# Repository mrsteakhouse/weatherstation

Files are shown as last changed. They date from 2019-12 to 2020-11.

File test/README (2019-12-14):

This directory is intended for PIO Unit Testing and project tests.

Unit Testing is a software testing method by which individual units of
source code, sets of one or more MCU program modules together with associated
control data, usage procedures, and operating procedures, are tested to
determine whether they are fit for use. Unit testing finds problems early
in the development cycle.

More information about PIO Unit Testing:
- https://docs.platformio.org/page/plus/unit-testing.html

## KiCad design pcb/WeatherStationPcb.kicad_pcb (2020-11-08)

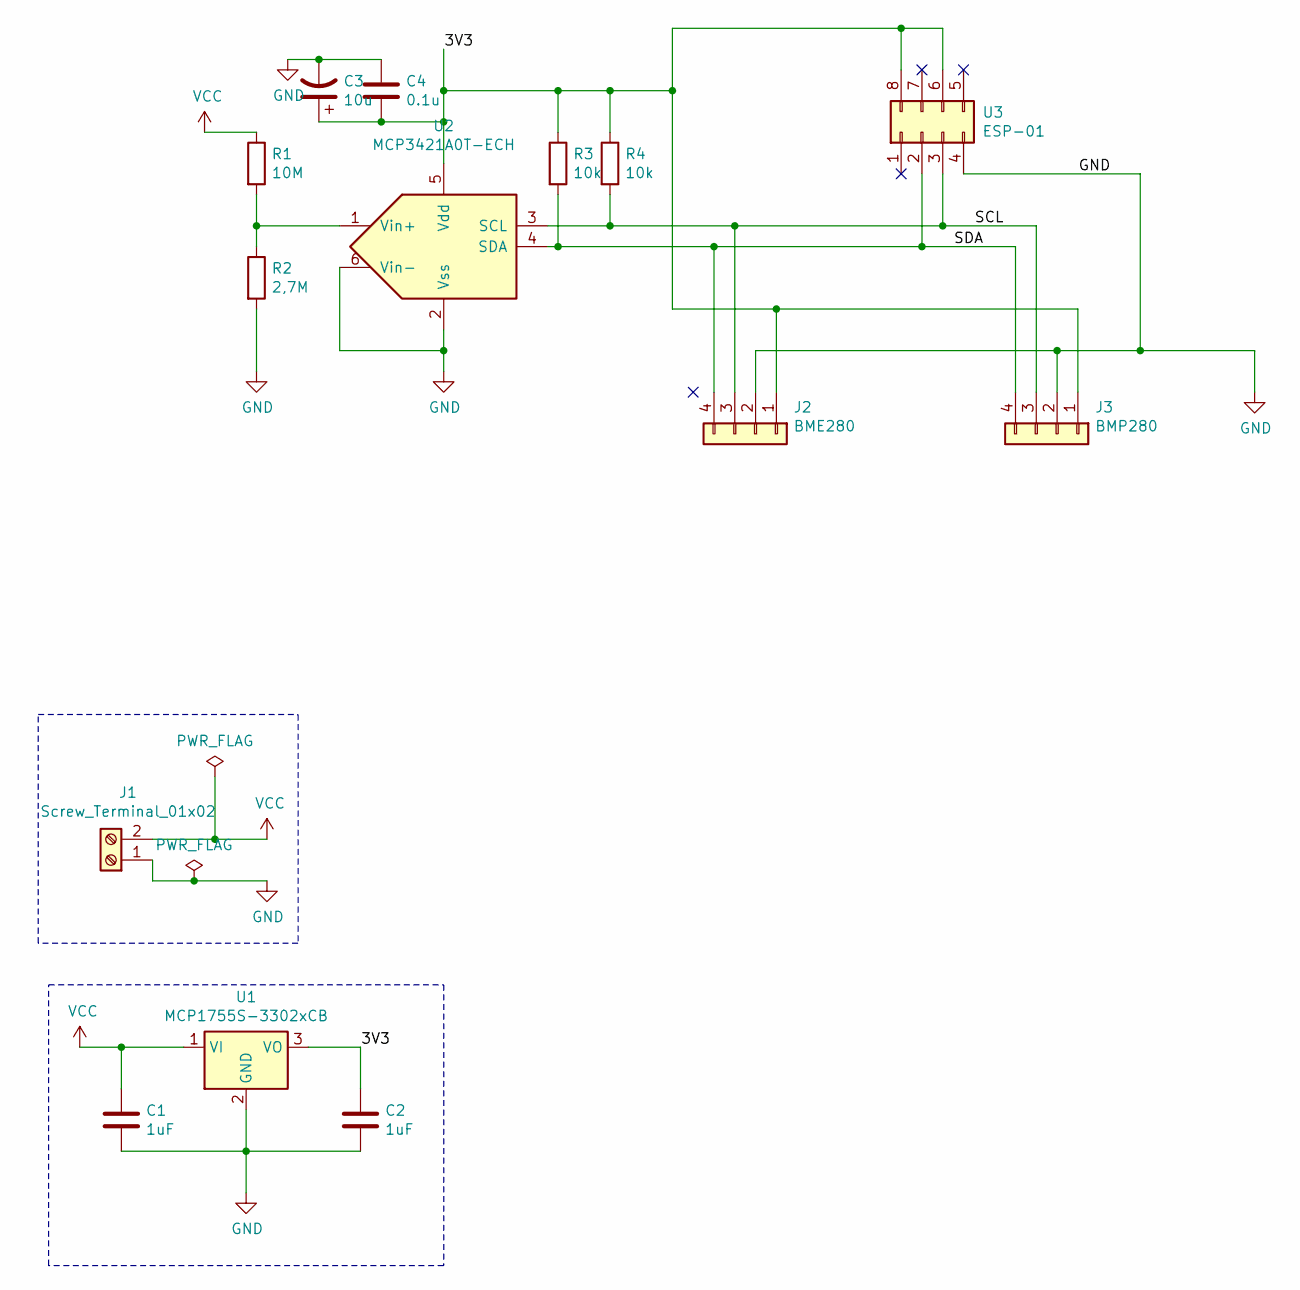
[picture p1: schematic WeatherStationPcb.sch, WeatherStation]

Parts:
C1, C2: 1uF; C_0805_2012Metric_Pad1.15x1.40mm_HandSolder
C3: 10u; CP_EIA-6032-28_Kemet-C_Pad2.25x2.35mm_HandSolder
C4: 0.1u; C_0805_2012Metric_Pad1.15x1.40mm_HandSolder
J1: Screw_Terminal_01x02; TerminalBlock_bornier-2_P5.08mm
J2: BME280; PinSocket_1x04_P2.54mm_Vertical
J3: BMP280; PinSocket_1x04_P2.54mm_Vertical
R1: 10M; R_0805_2012Metric_Pad1.15x1.40mm_HandSolder
R2: 2,7M; R_0805_2012Metric_Pad1.15x1.40mm_HandSolder
R3, R4: 10k; R_0805_2012Metric_Pad1.15x1.40mm_HandSolder
U1: MCP1755S-3302xCB; SOT-223
U2: MCP3421A0T-ECH; SOT-23-6_Handsoldering
U3: ESP-01

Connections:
/3V3: C2.1, C3.1, C4.1, J2.1, J3.1, R3.1, R4.1, U1.3 (VO), U2.5 (Vdd), U3.6 (CH_PD), U3.8 (VCC)
/SCL: J2.3, J3.3, R4.2, U2.3 (SCL), U3.3 (GPIO2)
/SDA: J2.4, J3.4, R3.2, U2.4 (SDA), U3.2 (GPIO0)
GND: C1.2, C2.2, C3.2, C4.2, J1.1, J2.2, J3.2, R2.2, U1.2 (GND), U2.2 (Vss), U2.6 (Vin-), U3.4 (GND)
unnamed: R1.2, R2.1, U2.1 (Vin+)
VCC: C1.1, J1.2, R1.1, U1.1 (VI)

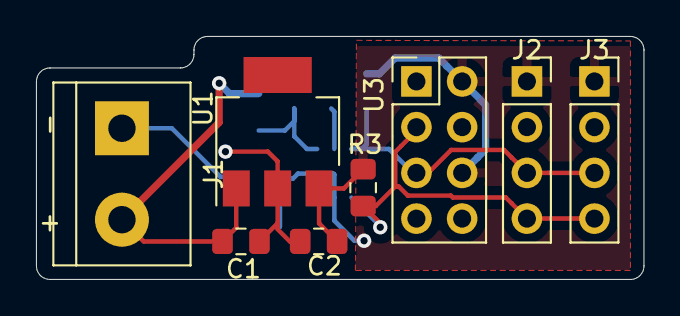
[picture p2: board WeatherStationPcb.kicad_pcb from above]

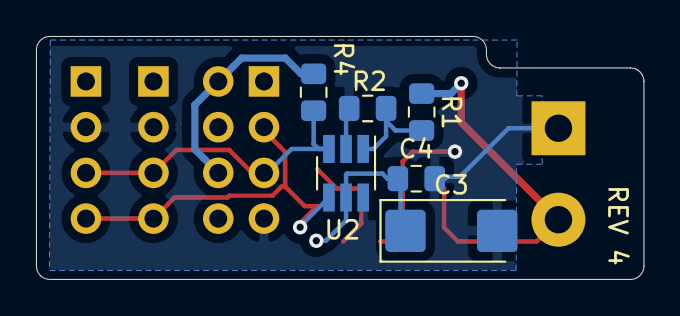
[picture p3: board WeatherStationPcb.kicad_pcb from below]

Board: 2 copper layers, 33.8 x 13.5 mm, 14 parts (6 on the bottom side), 6 nets.

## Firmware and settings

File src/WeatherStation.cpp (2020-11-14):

#include <ESP8266WiFi.h>

#include <WebThingAdapter.h>

#include <Wire.h>
#include <Adafruit_BME280.h>
#include <Adafruit_BMP280.h>
#include <Adafruit_Sensor.h>

#include <SetWifiCredentials.h>
#include <PubSubClient.h>
#include <sstream>
#include <MCP342X.h>

#define LSB 0.0000625
#define FACTOR 9.104

Adafruit_BME280 bme;
Adafruit_BMP280 bmp;

WiFiClient espClient;
PubSubClient client(espClient);

const IPAddress mqttServer = IPAddress(192, 168, 0, 59);

static const char *const DEVICE = "living-room-temp";
static const char *const TEMPERATURE_NODE = "temperature";
static const char *const TEMP_PROPERTY = "temp";
static const char *const HUMIDITY_PROPERTY = "hum";
static const char *const PRESSURE_PROPERTY = "p";
static const char *const BATTERY_PROPERTY = "bat";
static const char *const ALARM_PROPERTY = "alarm";
static const char *const PUMP_NODE = "pump";
uint64_t sleepTime = 3600e6L;

MCP342X adc;

void setupNetwork();

void setupSensors();

void setupAdapter(const IPAddress &ip);

void connectMqtt();

void updateValues();

void sendValue(const char* node, const char* property, const char* value);

void setupSleep();

std::string doubleToString(double number);

void setup(void)
{
    Serial.begin(115200);
    setupNetwork();
    IPAddress ip = WiFi.localIP();
    Serial.print(FPSTR("IP="));
    Serial.println(ip);

    setupSensors();
    connectMqtt();
}

void setupNetwork()
{
    setWifiCredentials();
    delay(20);

    WiFi.persistent(false);
    WiFi.mode(WIFI_STA);
    WiFi.setAutoConnect(false);
    WiFi.disconnect();
    IPAddress ip(192, 168, 0, 227);
    IPAddress gateway(192, 168, 0, 1);
    IPAddress subnet(255, 255, 255, 0);
    WiFi.config(ip, gateway, gateway, subnet);

    WiFi.begin(Ssid, Password);

    int retryCounter = 0;
    while (WiFi.status() != WL_CONNECTED)
    {
        delay(500);
        Serial.print(".");

        if (retryCounter >= 20)
        {
            ESP.restart();
        }

        retryCounter++;
    }

    Serial.println("");
    Serial.println(FPSTR("WiFi connected"));
}

void setupSensors()
{
    Wire.begin(0, 2);

    delay(1000);

    if (!bmp.begin(0x77))
    {
        Serial.println(FPSTR("Could not find a valid BMP280 sensor"));
        ESP.restart();
    }
    if (!bme.begin(0x76))
    {
        Serial.println(FPSTR("Could not find a valid BME280 sensor"));
        ESP.restart();
    }

    bmp.setSampling(Adafruit_BMP280::MODE_NORMAL,
                    Adafruit_BMP280::SAMPLING_NONE,
                    Adafruit_BMP280::SAMPLING_X1,
                    Adafruit_BMP280::FILTER_OFF,
                    Adafruit_BMP280::STANDBY_MS_125);
    delay(20);
    bme.setSampling(Adafruit_BME280::MODE_FORCED,
                    Adafruit_BME280::SAMPLING_X16,
                    Adafruit_BME280::SAMPLING_X1,
                    Adafruit_BME280::SAMPLING_X8,
                    Adafruit_BME280::FILTER_OFF,
                    Adafruit_BME280::STANDBY_MS_125);
    delay(20);

    adc.configure( MCP342X_MODE_ONESHOT |
                     MCP342X_CHANNEL_1 |
                     MCP342X_SIZE_16BIT |
                     MCP342X_GAIN_1X);
}

void connectMqtt()
{
    client.setServer(mqttServer, 1883);
    int retryCounter = 0;
    String clientId = "living-room-weatherstation";
    Serial.println(FPSTR("Connect to MQTT Broker"));
    while(!client.connected() && retryCounter < 5)
    {
        if (client.connect(clientId.c_str()))
        {
            Serial.println(FPSTR("connection established"));
            return;
        }

        Serial.println(FPSTR("Connection failed, retry in 1s"));
        retryCounter++;
        delay(1000);
    }

    Serial.println(FPSTR("No connection to MQTT Broker"));
}

void loop(void)
{
    updateValues();

    setupSleep();
//    delay(2000);
}

void updateValues()
{
    bme.takeForcedMeasurement();
    double temp = bme.readTemperature();
    double hum = bme.readHumidity();
    double pr = bme.readPressure() / 100.0F;
    double pp = bmp.readPressure() / 100.0F;

    static int16_t  result;
    adc.startConversion();
    adc.getResult(&result);
    double bat = FACTOR * result * (double) (LSB / 1.0);

    bool isAlarm = pp - pr > 5;

    sendValue(TEMPERATURE_NODE, TEMP_PROPERTY, doubleToString(temp).c_str());
    delay(20);
    sendValue(TEMPERATURE_NODE, HUMIDITY_PROPERTY, doubleToString(hum).c_str());
    delay(20);
    sendValue(TEMPERATURE_NODE, PRESSURE_PROPERTY, doubleToString(pr).c_str());
    delay(20);
    sendValue(PUMP_NODE, ALARM_PROPERTY, isAlarm ? "true" : "");
    delay(20);
    sendValue(TEMPERATURE_NODE, BATTERY_PROPERTY, doubleToString(bat).c_str());
    delay(20);
    

#ifdef DEBUG
    Serial.print(FPSTR("Temperature = "));
    Serial.print(temp);
    Serial.println(" *C");

    Serial.print(FPSTR("Pressure = "));
    Serial.print(pr);
    Serial.println(FPSTR(" hPa"));

    Serial.print(FPSTR("Humidity = "));
    Serial.print(hum);
    Serial.println(FPSTR(" %"));

    Serial.print(FPSTR("Pump Pressure = "));
    Serial.print(pp);
    Serial.println(FPSTR(" hPa"));
#endif
}

void sendValue(const char* node, const char* property, const char* value)
{
    char topicBuffer[128];
    sprintf(topicBuffer, "homie/%s/%s/%s", DEVICE, node, property);
#ifdef DEBUG
    Serial.print(FPSTR("Publishing to: "));
    Serial.println(topicBuffer);
#endif
    client.publish(topicBuffer, value, true);
}

void setupSleep()
{
    bmp.setSampling(Adafruit_BMP280::MODE_SLEEP);
    bme.setSampling(Adafruit_BME280::MODE_SLEEP);
    Wire.flush();

    Serial.println(FPSTR("Sleeping now"));
    ESP.deepSleep(sleepTime, RFMode::RF_NO_CAL);
    delay(100);
}

std::string doubleToString(double number)
{
    std::ostringstream stream;
    stream << number;
    return stream.str();
}

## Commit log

2020-05-20 feat(*): add pcb design
    [WeatherStationPcb-B_Cu.gbr, WeatherStationPcb-B_Mask.gbr, WeatherStationPcb-B_Paste.gbr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]
2020-11-01 feat(homie): add mqtt message specification for weather station device
2020-11-01 feat(pcb): update pcb
    [WeatherStationPcb.kicad_pcb, WeatherStationPcb.sch]
2020-11-02 fix(*): change settings for better measurements
    [WeatherStation.cpp]
2020-11-02 fix(sleepTime): fix the sleep time
    [WeatherStation.cpp]
2020-11-02 fix(WeatherStation.cpp): take value from framework since sensor settings now deliver accurate values
    [WeatherStation.cpp]
2020-11-08 feat(pcb): update the pcb by adding voltage sensor
    [WeatherStationPcb.kicad_pcb, WeatherStationPcb.sch]
2020-11-14 feat(*): add support for battery levels
    [WeatherStationPcb.sch]
2020-11-14 feat(WeatherStation.cpp): move device id to constant
